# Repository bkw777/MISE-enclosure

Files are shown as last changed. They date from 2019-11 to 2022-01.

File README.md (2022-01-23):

## Enclosure for Peter Bartlett's MISE and M3SE.
http://bartlettlabs.com/MISE/index.html  
http://bartlettlabs.com/M3SE/index.html

Alt text for your video (https://youtu.be/Me62yHelnyM)

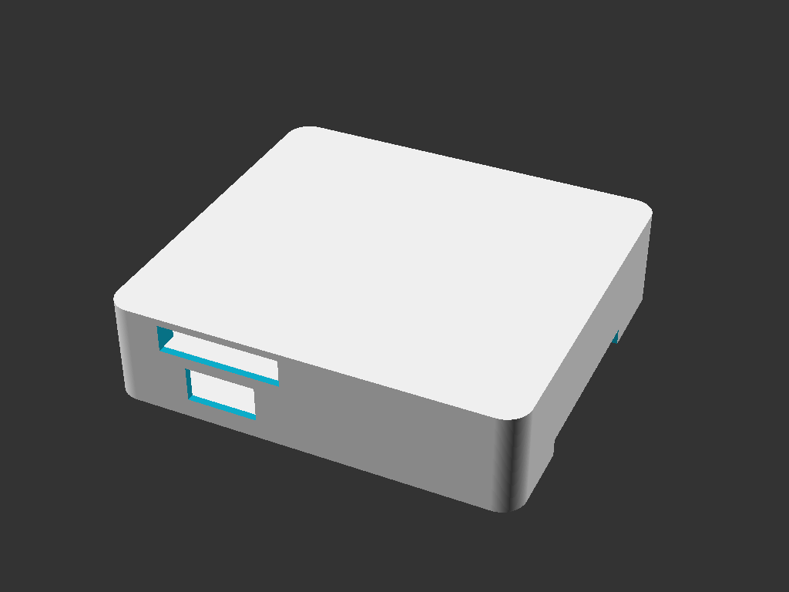
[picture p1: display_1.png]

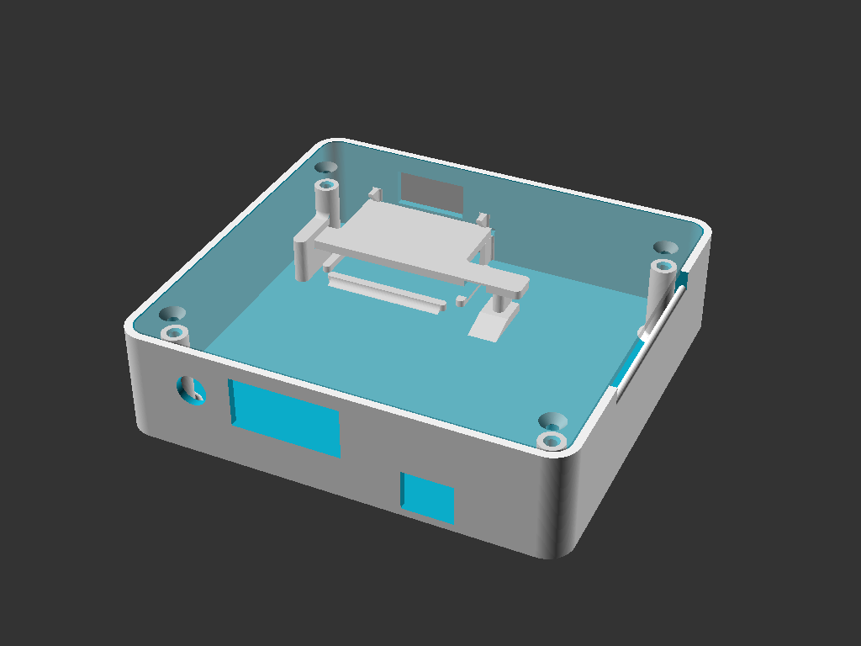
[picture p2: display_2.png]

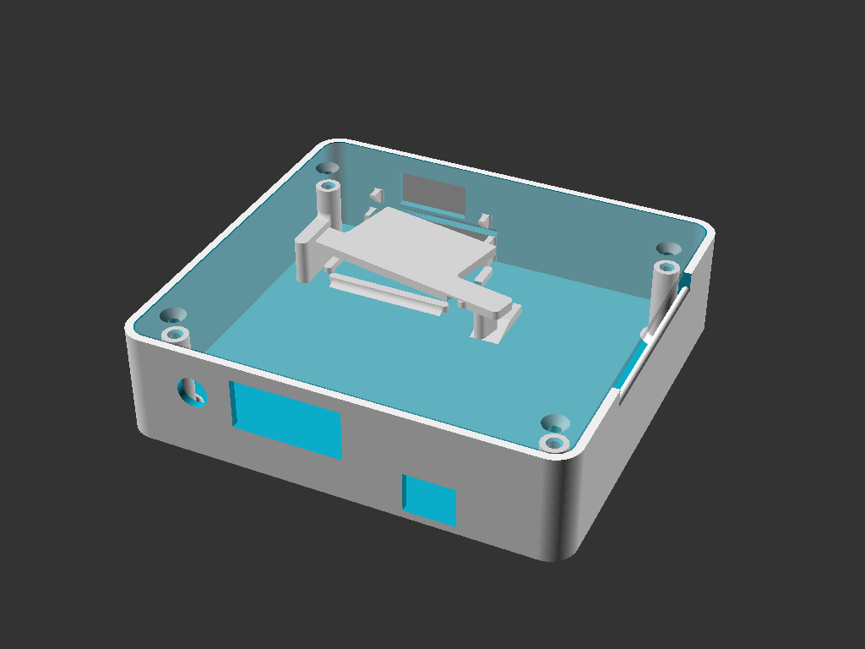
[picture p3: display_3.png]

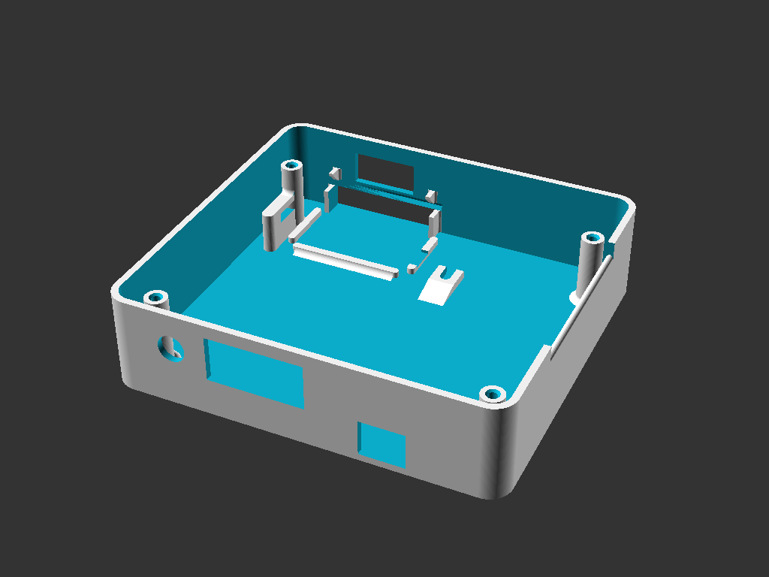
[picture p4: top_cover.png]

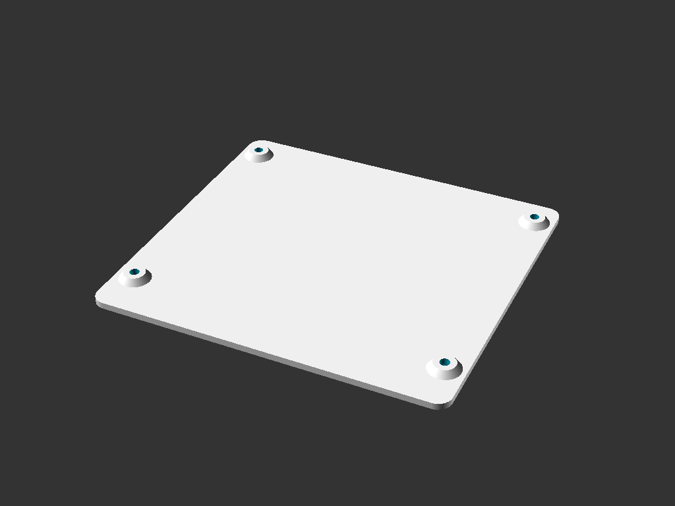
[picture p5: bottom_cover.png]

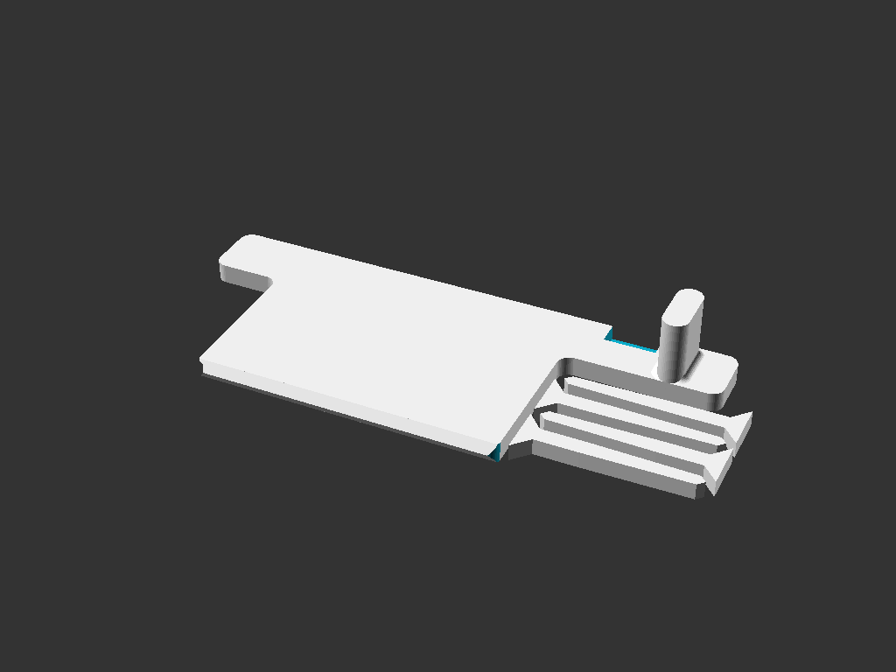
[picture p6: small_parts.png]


Pictures: https://photos.app.goo.gl/1NdcbL9hprvxRTdB7

STL files for 3d-printing are in [releases](../../releases/latest)

### Directions:

#### 1 - print the 3 files
 MISE_M3SE_top_cover_\<version\>.stl  
 MISE_M3SE_bottom_cover_\<version\>.stl  
 MISE_M3SE_small_parts_\<version\>.stl
 
 PLA, 20% infill, 3 walls is fine.

 Or buy a print from [CraftCloud](https://craftcloud3d.com/offer/18893031-29e2-49f1-acdd-6c543ac05efc)

#### 2 - Aquire the following parts

* **1 40-pin "IDE" male-female extension cable, 4 inch length**  
 It needs to be an extension, with one male and one female connector.  
 The direction the cable exits the connector on the *male* end matters. The cable should go *away* from the key notch in the side of the connector.  
 No extra fold / strain relief clip on the male connector.  
 No special requirements for the female connector.  
 
 http://www.cablesonline.com/240pinidedir.html  
 Change “Available Lengths: 4 inches FI-004”

* **4 flat-head #6 x 3/4" screws**  
 (These screws are optional: There are printed "nails" included in the small_parts stl which can be used in place of screws)  
 Home Depot:  
 https://www.homedepot.com/p/Everbilt-6-32-x-3-4-in-Phillips-Flat-Head-Stainless-Steel-Machine-Screw-6-Pack-814561/204274823

* **4 small rubber feet**  
 http://www.homedepot.com/p/Everbilt-1-2-in-Self-Adhesive-Vinyl-Surface-Bumpers-16-per-Pack-49967/203661150

#### 3 - Assembly
Unplug the CF reader from the mainboard & remove the CF card(s) from the reader.

Remove the 4 nylon stand-offs from the screw holes on the mainboard.

Plug the male end of the IDE extension cable onto the CF reader.

Lay the CF reader flat in the small tray formed into the corner of the top_cover, with the lights and jumpers up facing you.  
Install the retainer over top of the CF reader. (refer to pics)

Orient the top cover so that the network, vga, & power side is away from you.  
Set the mainboard standing up behind the 2 rear screw posts, network/vga/power side down.  

Connect the free end of the IDE extension cable to the IDE plug on the mainboard.

Lift the mainboard up from behind the 2 rear screw posts, tip forward toward yourself, and lay the mainboard flat atop all 4 screw posts.

Place the bottom cover on top of the mainboard, with the 4 short risers pointing down.

Install the 4 screws.

### Painting
A very close off-the-shelf match to the RCA "Mercedes Silver" TRS-80 paint is
[Dupli-Color Bumper Coating FB108 Medium Silver](http://www.amazon.com/Dupli-Color-FB108-Medium-Flexible-Coating/dp/B00296DXN4).

## Author / License

<br />This work is licensed under a <a rel="license" href="http://creativecommons.org/licenses/by-sa/4.0/">Creative Commons Attribution-ShareAlike 4.0 International License</a>.  
Brian K. White - b.kenyon.w@gmail.com

Designed with [OpenSCAD](https://www.openscad.org/)

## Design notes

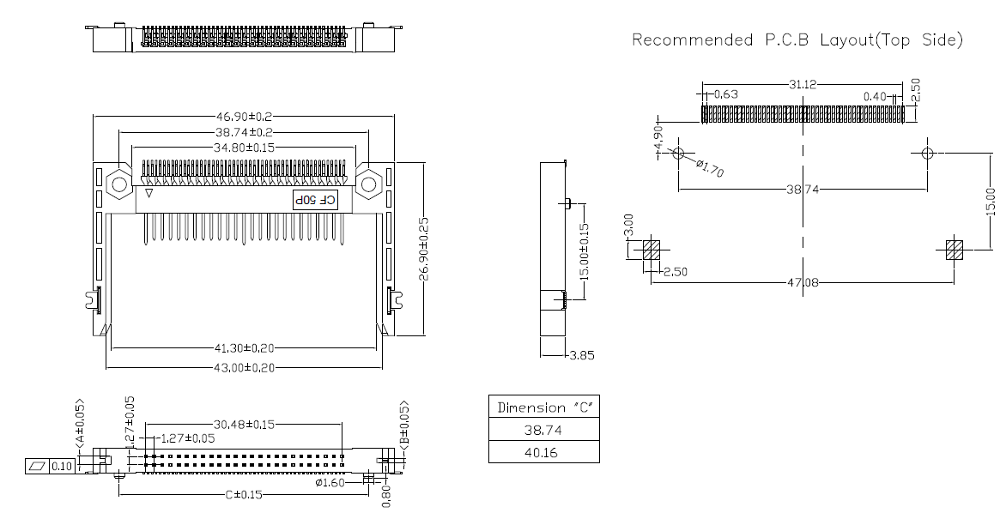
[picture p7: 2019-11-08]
ref/CF-50P.png

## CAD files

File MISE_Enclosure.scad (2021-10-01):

// M1SE/M3SE Enclosure - Top Cover
// b.kenyon.w@gmail.com

// Which version to generate, M1SE or M3SE
// The only difference is the width of the slot for the bus cable.
// M1SE has a 40-wire cable, M3SE has a 50-wire cable.
// M3SE version can be used for both M3SE and M1SE.
variant="M3SE";

// PCB dimensions
// https://groups.yahoo.com/neo/groups/TRS80MISE/conversations/topics/157
//  >  All hole centers are 250 mils from card edges, drilled for 187 mil board feet.
//  >  "Short edge" holes centered 3815 mils apart.
//  >  "Long edge" holes centered 4770 mils apart.
//  >  Thus the PCB is 4315x5270 mils.
px = 133.858; // pcb x len
py = 109.601; // pcb y len
pz = 0.1 + 1.6 + 0.1;     // pcb thickness
mi = 6.35;    // mounting holes inset from pcb edges
mhd = 4.75;   // mount hole diameter

// rear wall holes
vga_w = 35.814;
vga_h = 17.018;
vga_xc = -14.99;  // pcb X center to vga X center
vga_zb = -2.032;  // pcb Z top to vga Z bottom
pwr_r = 5.08;     // power radius
pwr_xc = -45.847; // pcb X center to power X center
pwr_zc = 6.604;   // pcb Z top to power Z center
nic_w = 16.51;
nic_h = 13.462;
nic_xc = 29.972;  // pcb X center to nic X center
nic_zt = 26.67;   // pcb Z top to nic Z top - NIC conector is the tallest top-side component, so normally you want "th" and "iw_h" to just copy this

// front wall holes
joy_h = 12.7;     // joystick height
joy_w = 22.86;    // joystick width
joy_xc = -30; // pcb center to js center
                  // joystick bottom = pcb top
joy_f = 5.1;      // pcb front edge to joystick front

cf_connector_thickness = 3.85 ; // references/CF-50P.png
cf_h = 0.1 + cf_connector_thickness + 0.1 + pz + 0.1 + cf_connector_thickness + 0.1 ; // cf height 9.9
cf_w = 43.18;    // cf width
                 // cf top = inside top surface = iw_h
cf_xc = joy_xc;  // cf x center

// right wall holes
bus_cable_conductors = (variant=="M1SE") ? 40 : 50;
bus_w = bus_cable_conductors * 1.27 + 1; // bus cable width
bus_h = 6.35;   // bus cable height
bus_yc = -5.33; // pcb center to bus cable center
                // bus cable z bottom = ew_z bottom

bch = 2.54;    // bottom-side components height - height of tallest bottom-side component (screw heads for heat sinks and connectors) from pcb bottom - inner/upper surface of base_plate rests here
tch = nic_zt;  // top-side components height - height of tallest top-side component (ethernet port) above pcb top - inner/lower surface of top wall rests here
assert(tch>=nic_zt,"tch must be >= nic_zt");
wt = 2.54;     // wall thickness - 2.54 makes the face of the ethernet port flush with the exterior surface

// NIC module pcb extends beyond the main pcb rear edge by this much.
// Rear vertical wall can be no closer to the main pcb than this.
// This just the nic module pcb,
// not including the rj45 connector which extends futher.
nic_pcb_overhang = 6.35; // nic module pcb overhang beyond main pcb edge

// FPGA module pcb extends past main pcb front edge by this much.
// Front vertical wall can be no closer to the main pcb than this.
fpga_pcb_overhang = 12.192; // fpga module pcb overhang beyond main pcb edge

// pcb edges to inside walls
f2w = fpga_pcb_overhang; // front pcb edge to front inside wall - must be fpga_pcb_overhang or greater
assert(f2w>=fpga_pcb_overhang,"f2w must be >= fpga_pcb_overhang");
l2w = 2;                 // left  pcb edge to left  inside wall - mise v1.1 has a heat-sink that overhangs about one mm or less on the left - v1.2 has no overhangs on the left
r2w = 2;                 // right pcb edge to right inside wall - no overhangs on the right, but the bus cable passes between the pcb and the wall.
assert(r2w>=1,"r2w must be enough to allow the bus cable to fit between the pcb and the enclosure wall.");
b2w = nic_pcb_overhang;  // back  pcb edge to back  inside wall - must be nic_pcb_overhang or greater
assert(b2w>=nic_pcb_overhang,"b2w must be >= nic_pcb_overhang");

// screw posts and countersinks
screw_d = 3.5;  // screw diameter - #6 = 0.14" = 3.5
screw_fhr = 4 ; // flat head radius
spir = screw_d/2-0.1; // screw post inside radius
spor = spir+2.5; // screw post outside radius

// interior walls
iw_x = l2w + px + r2w;
iw_y = f2w + py + b2w;
// This controls how high the top is above the highest component
iw_h = tch; // interior walls height - may be "tch" or greater
assert(iw_h>=tch,"iw_h must be >= tch");
iw_z = wt + bch + pz + iw_h; // total interior wall height

// exterior walls
ew_x = wt + iw_x + wt;  // total exterior X width
ew_y = wt + iw_y + wt;  // total exterior Y depth
ew_z = iw_z + wt;       // total exterior Z height

// wall corners radius, 0 to 13
// 0 = square corners
// 0.001 = square inside, round outside thickness of walls
// >0 = round corners
// >13 = invalid, hits pcb corners
cr = 6; // vertical corners inside radius

oc = 0.1;  // overcut - extend subtraction shapes past the edges of the shapes they cut from, to avoid making zero-thickness features
twt = 1.6; // tunnel wall thickness
p2t = 0.5; // any pcb edge pcb to any tunnel end

joy_t = f2w-joy_f-p2t; // joystick tunnel length

// CF reader
cft_w = 47.3; // cf tray inside width
cft_d = 27.3; // cf tray inside depth

// This controls how far the CF cards stick out of the front of the enclosure.
// This can vary from 0 to almost 9 in theory. (at 9 you would need fingernails to get the CF cards out)
cft_f2w = 5.842;  // cf tray inside front to inside front wall
//cft_f2w = 0;
                  // cf tray X center = cf opening X center = js_xc
cft_wt = 2.4;     // cf tray wall thickness
cft_wh = 2.54;    // cf tray wall height

cft_ow = cft_wt+cft_w+cft_wt; // cf tray outer walls
cft_otw = twt+cf_w+twt;       // cf tunnel outer walls

cft_cny = 4.83;    // cf tray clearance notch, inner tray rear to notch side
cft_cnl = 10.66;   // cf tray clearance notch, width
cft_cnh = 1.27;    // cf tray clearance notch, floor height (top wall inner surface to notch floor)

// cf reader retainer
// cf reader retainer top - cr_top is special
// The back side of the FPGA board comes down very close to the top of the JP2 jumper on the card reader.
// cr_top should be as high as possible, touching the FPGA board.
// This should allow about 1mm of plastic to cover the top of JP2 and act as a barrier to prevent JP2 from touching and shorting on the FPGA board.
// If really needed, you can increase iw_h, which will increase the distance between the fpga board and the card reader.
cr_top = 13; // highest surface on retainer bar

// cf retainer lid thickness
cr_lt = cr_top - cf_h;

cr_tab_w = 10;
cr_tab_wt = 3; // wall thickness around tab, all directions
//cr_tab_pocket_wall_thickness = spor*2;
cr_tab_pocket_wall_thickness = 6;
cr_tab_locx = px/2+cf_xc-mi-cft_w/2; // centered on screw post
cr_tab_pocket_wall_height = cr_top + 3;
cr_leg_w = 4;  // leg thickness
cr_tab_len = cr_tab_locx + cr_tab_pocket_wall_thickness/2; // for flush end, add "-cr_leg_w/2"
p_wall_y1 = f2w + mi;  // pocket wall front
p_wall_y2 = cft_f2w + cft_d + 5;  // pocket wall back
cr_tab_pocket_wall_length = p_wall_y2 - p_wall_y1;

// TODO - re-arrange this to be based off the edge of the reader pcb
//        this dim is left over from the previous style with a foot tab that goes into a pocket
// cf retainer latch block
cr_latch_locx = 18; // tray side to pocket side
cr_latch_handle = 12; // retainer bar extends past leg to make a finger-pull-able overhang

// smoother curves (less vibration while printing)
$fa = 0.5; // facet angle
$fs = 0.4; // facet size


///////////////////////////////////////////////////

module mirror_copy(vector){
  children();
  mirror(vector) children();
}

module walls() {
  difference() {
    group() { // add
      // exterior walls
      if(cr<=0) translate([-l2w-wt,-f2w-wt,-pz-bch-wt]) cube([ew_x,ew_y,ew_z]); // square corners
      else hull() {                                                             // round corners
        translate([-l2w+cr,-f2w+cr,-pz-bch-wt]) cylinder(ew_z,cr+wt,cr+wt);
        translate([px+r2w-cr,-f2w+cr,-pz-bch-wt]) cylinder(ew_z,cr+wt,cr+wt);
        translate([-l2w+cr,py+b2w-cr,-pz-bch-wt]) cylinder(ew_z,cr+wt,cr+wt);
        translate([px+r2w-cr,py+b2w-cr,-pz-bch-wt]) cylinder(ew_z,cr+wt,cr+wt);
      }

    } // add
    group() { // remove
      // interior walls
      if(cr<=0) translate([-l2w,-f2w,-pz-bch-wt-wt]) cube([iw_x,iw_y,ew_z]);  // square corners
      else hull() {                                                           // round corners
        translate([-l2w+cr,-f2w+cr,-pz-bch-wt-oc]) cylinder(ew_z-wt+oc,cr,cr);
        translate([px+r2w-cr,-f2w+cr,-pz-bch-wt-oc]) cylinder(ew_z-wt+oc,cr,cr);
        translate([-l2w+cr,py+b2w-cr,-pz-bch-wt-oc]) cylinder(ew_z-wt+oc,cr,cr);
        translate([px+r2w-cr,py+b2w-cr,-pz-bch-wt-oc]) cylinder(ew_z-wt+oc,cr,cr);
      }
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

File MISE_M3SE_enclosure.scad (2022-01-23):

// M1SE/M3SE Enclosure - Top Cover
// b.kenyon.w@gmail.com
// version: 2.2.005

// Which version to generate, M1SE or M3SE
// The only difference is the width of the slot for the bus cable.
// M1SE has a 40-wire cable, M3SE has a 50-wire cable.
// M3SE version can be used for both M3SE and M1SE.
variant = "M3SE";

// Normally Makefile sets this.
// "none", "top_cover", "bottom_cover", "retainer", "nail", "small_parts"
// "display_1", "display_2", "display_3", "display_nail"
make = "display_2";

$fs = 0.25;
$fa = 1;
o = 0.01; // overlap/overcut - extend unions/cuts past boundaries
fc = 0.1; // part fitment clearance
fr = 1;   // default fillet radius

// PCB dimensions
// https://groups.yahoo.com/neo/groups/TRS80MISE/conversations/topics/157
//  >  All hole centers are 250 mils from card edges, drilled for 187 mil board feet.
//  >  "Short edge" holes centered 3815 mils apart.
//  >  "Long edge" holes centered 4770 mils apart.
//  >  Thus the PCB is 4315x5270 mils.
px = 133.858; // pcb x len
py = 109.601; // pcb y len
pcb_thickness = 1.6;
pz = fc + pcb_thickness + fc;
mi = 6.35;    // mounting holes inset from pcb edges
mhd = 4.75;   // mount hole diameter

// rear wall holes
vga_w = 35.814;
vga_h = 17.018;
vga_xc = -14.99;  // pcb X center to vga X center
vga_zb = -2.032;  // pcb Z top to vga Z bottom
pwr_r = 5.08;     // power radius
pwr_xc = -45.847; // pcb X center to power X center
pwr_zc = 6.604;   // pcb Z top to power Z center
nic_w = 16.51;
nic_h = 13.462;
nic_xc = 29.972;  // pcb X center to nic X center
nic_zt = 26.67;   // pcb Z top to nic Z top - NIC conector is the tallest top-side component, so normally you want "th" and "iw_h" to just copy this

// front wall holes
joy_h = 12.7;     // joystick height
joy_w = 25; //22.86;    // joystick width
joy_xc = -30;     // pcb center to js center
                  // joystick bottom = pcb top
joy_f = 5.1;      // pcb front edge to joystick front

cf_connector_thickness = 3.85 ; // references/CF-50P.png
cf_h = 0.1 + cf_connector_thickness + 0.1 + pz + 0.1 + cf_connector_thickness + 0.1 ; // cf height 9.9
cf_w = fc+43.1+fc;    // cf width
                 // cf top = inside top surface = iw_h
cf_xc = joy_xc;  // cf x center

// right wall holes
bus_cable_conductors = (variant=="M1SE") ? 40 : 50;
bus_w = bus_cable_conductors * 1.27 + 1; // bus cable width
bus_h = 6.35;   // bus cable height
bus_yc = -5.33; // pcb center to bus cable center
                // bus cable z bottom = ew_z bottom

bch = 2.54;    // bottom-side components height - height of tallest bottom-side component (screw heads for heat sinks and connectors) from pcb bottom - inner/upper surface of base_plate rests here
tch = nic_zt;  // top-side components height - height of tallest top-side component (ethernet port) above pcb top - inner/lower surface of top wall rests here
assert(tch>=nic_zt,"tch must be >= nic_zt");
wt = 2.54;     // wall thickness - 2.54 makes the face of the ethernet port flush with the exterior surface

// NIC module pcb extends beyond the main pcb rear edge by this much.
// Rear vertical wall can be no closer to the main pcb than this.
// This just the nic module pcb,
// not including the rj45 connector which extends futher.
nic_pcb_overhang = 6.35; // nic module pcb overhang beyond main pcb edge

// FPGA module pcb extends past main pcb front edge by this much.
// Front vertical wall can be no closer to the main pcb than this.
fpga_pcb_overhang = 12.192; // fpga module pcb overhang beyond main pcb edge

// pcb edges to inside walls
f2w = fpga_pcb_overhang; // front pcb edge to front inside wall - must be fpga_pcb_overhang or greater
assert(f2w>=fpga_pcb_overhang,"f2w must be >= fpga_pcb_overhang");
l2w = 2;                 // left  pcb edge to left  inside wall - mise v1.1 has a heat-sink that overhangs about one mm or less on the left - v1.2 has no overhangs on the left
r2w = 2;                 // right pcb edge to right inside wall - no overhangs on the right, but the bus cable passes between the pcb and the wall.
assert(r2w>=1.27,"r2w must be enough to allow the bus cable to fit between the pcb and the enclosure wall.");
b2w = nic_pcb_overhang;  // back  pcb edge to back  inside wall - must be nic_pcb_overhang or greater
assert(b2w>=nic_pcb_overhang,"b2w must be >= nic_pcb_overhang");

// screw posts and countersinks
screw_d = 3.5;  // screw diameter - #6 = 0.14" = 3.5
screw_fhr = 4 ; // flat head radius
spir = screw_d/2-0.1; // screw post inside radius
spor = spir+2.5; // screw post outside radius
screw_post_fillet = 2.5;
screw_post_chamfer = 0.75;

// printable flat nail that can be used in place of screw
// nail length not counting head
nail_length = 20 + pcb_thickness + bch;

// square nail cross-section diagonal width, percent of screw post ID
// 0 = corners of nail body exactly the same is screw hole ID
// -n = diagonal x% smaller than hole
// +n = diagonal x% larger than hole
nail_interference_fit_percent = 10;

// how far the full-width non-tapered part of the nail shank inserts into the screw post
// 0 = nail is only full width in the PCB and bottom cover
//     tapers from 75% to full width over the remaining length
nail_grip_depth = 0;

nail_full_width = sq_in_circle(spir*2) * (100+nail_interference_fit_percent)/100;
nail_tip_width = nail_full_width * 0.75;

// interior walls
iw_x = l2w + px + r2w;
iw_y = f2w + py + b2w;
// This controls how high the top is above the highest component
iw_h = tch; // interior walls height - may be "tch" or greater
assert(iw_h>=tch,"iw_h must be >= tch");
iw_z = wt + bch + pz + iw_h; // total interior wall height

// exterior walls
ew_x = wt + iw_x + wt;  // total exterior X width
ew_y = wt + iw_y + wt;  // total exterior Y depth
ew_z = iw_z + wt;       // total exterior Z height

// wall corners radius, 0 to 13
// 0 = square corners
// 0.001 = square inside, round outside thickness of walls
// >0 = round corners
// >13 = invalid, hits pcb corners
cr = 6; // vertical corners inside radius

twt = 2; // tunnel wall thickness
p2t = 0.5; // any pcb edge pcb to any tunnel end

joy_t = f2w-joy_f-p2t; // joystick tunnel length

// CF reader
cft_w = 47.3; // cf tray inside width
cft_d = 27.3; // cf tray inside depth

// This controls how far the CF cards stick out of the front of the enclosure.
// This can vary from 0 to almost 9 in theory. (at 9 you would need fingernails to get the CF cards out)
cft_f2w = 5.842;  // cf tray inside front to inside front wall
//cft_f2w = 0;
                  // cf tray X center = cf opening X center = js_xc
cft_wt = 3;      // cf tray wall thickness
cft_wh = 2.4;    // cf tray wall height

cft_ow = cft_wt+cft_w+cft_wt; // cf tray outer walls
cft_otw = twt+cf_w+twt;       // cf tunnel outer walls

cft_cny = 4.83;    // cf tray clearance notch, inner tray rear to notch side
cft_cnl = 10.66;   // cf tray clearance notch, width
cft_cnh = 1.27;    // cf tray clearance notch, floor height (top wall inner surface to notch floor)

// cf reader retainer
// cf reader retainer top - cr_top is special
// The back side of the FPGA board comes down very close to the top of the JP2 jumper on the card reader.
// cr_top should be as high as possible, touching the FPGA board.
// This should allow about 1mm of plastic to cover the top of JP2 and act as a barrier to prevent JP2 from touching and shorting on the FPGA board.
// If really needed, you can increase iw_h, which will increase the distance between the fpga board and the card reader.
cr_top = 13; // highest surface on retainer bar

// cf retainer lid thickness
cr_lt = cr_top - cf_h;

cr_tab_w = 10; // retainer tab width
cr_tab_wt = 3; // wall thickness around tab
cr_tab_pocket_wall_thickness = 5; // spor*2;
cr_tab_locx = px/2+cf_xc-mi-cft_w/2; // centered on screw post
cr_tab_pocket_wall_height = cr_top + 3;
cr_leg_w = 4;  // leg thickness
cr_tab_len = cr_tab_locx + cr_tab_pocket_wall_thickness/2-cr_leg_w/2-fc; // for flush end, add "-cr_leg_w/2"
p_wall_y1 = f2w + mi;  // pocket wall front
p_wall_y2 = cft_f2w + cft_d + 5;  // pocket wall back
cr_tab_pocket_wall_length = p_wall_y2 - p_wall_y1;

// TODO - re-arrange this to be based off the edge of the reader pcb
//        this dim is left over from the previous style with a foot tab that goes into a pocket
// cf retainer latch block
cr_latch_locx = 18; // tray side to pocket side
cr_latch_handle = 6; // retainer bar extends past leg to make a handle

include <handy.scad>;

///////////////////////////////////////////////////

function sq_in_circle(d) = d * sqrt(2)/2;
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

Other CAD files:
handy.scad

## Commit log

2016-03-14 Initial commit. This version mostly works, but does need a little manual hacking after printing. The posts on the base plate should be shortened to 0.1 inch (just cut off the cylindrical post part an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
    [MISE_base_plate.FCStd, MISE_base_plate.stl, MISE_cf_retainer.FCStd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]
2016-03-14 Correct placement of front and rear wall openings. Move cf retainer closed slot closer to reader. Trim unnecessary height of cf retainer open slot post.. Lengthen and move forward cf retainer open sl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
    [MISE_base_plate.FCStd, MISE_base_plate.stl, MISE_top_cover.FCStd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]
2016-03-14 Round the 4 vertical outside corners to look more like trs-80 and accessories. (although, trs-80 and accessories round the horizontal front and rear edges, not the vertical edges)
    [MISE_base_plate.FCStd, MISE_base_plate.stl, MISE_top_cover.FCStd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]
2016-03-25 Removed junk extra line13 from cf retainer base sketch. Repaired cf retainer closed slot pocket sketch came off it's face. Adjusted length and shape of cf retainer open slot a little. Resolved confli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
2016-03-26 Main dimensions and shape adjusted for v1.2 enclosure. Also: * cutouts to allow retainer to swing far enough to install/remove o clearance for JP1 & JP2 o drop leg when twisted * solid block padding 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
    [MISE_cf_retainer.FCStd, MISE_cf_retainer.stl]
2016-04-22 Several corrections to cf retainer. M3SE option, only difference is wider ribbon cable opening.
    [M3SE_top_cover.stl, MISE_cf_retainer.FCStd, MISE_cf_retainer.stl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]
2019-10-07 initial .scad
    [Top_Cover.scad]
2019-10-11 conditional corners, show pcb, comments, smooth arcs
    [Top_Cover.scad]
2019-10-29 archive FreeCAD files, finish OpenSCAD model
    [M3SE_top_cover.stl, MISE_Enclosure.scad, MISE_base_plate.FCStd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]
2019-10-31 tweak the retainer bar tabs & slots
    [MISE_Enclosure.scad, bottom_cover.stl, retainer.stl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]
2019-11-02 strengthen retainer, adjust retainer fitment
    [MISE_Enclosure.scad, bottom_cover.stl, retainer.stl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]
2019-11-02 docs & images
    [MISE_Enclosure.scad, bottom_cover.stl, retainer.stl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]
2019-11-02 retainer heel clearance while opening/closing, screw posts id & od, bottom cover screw holes id
    [MISE_Enclosure.scad, bottom_cover.stl, retainer.stl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]
2019-11-04 new retainer design that's simpler to use and simpler to print
    [MISE_Enclosure.scad, bottom_cover.stl, retainer.stl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]
2019-11-04 retainer printing orientation
    [MISE_Enclosure.scad]
2019-11-04 update renders
    [bottom_cover.stl, retainer.stl, top_cover.stl]
2019-11-04 update retainer-open render
    [MISE_Enclosure.scad, bottom_cover.stl, retainer.stl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]
2019-11-08 remove difficult to print overhangs
    [MISE_Enclosure.scad, bottom_cover.stl, retainer.stl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]
2019-11-09 strengthen pocket wall against the force from the retainer bar twisting and prising the slot open. Add front lid guide. Increase clearance in latch around leg.
    [MISE_Enclosure.scad, bottom_cover.stl, retainer.stl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]
2019-11-09 fix retainer position in renders
    [MISE_Enclosure.scad, bottom_cover.stl, top_cover.stl]
2019-11-12 replace some right-angles in the cf-tray with round ends to make it more FDM friendly.
    [MISE_Enclosure.scad, bottom_cover.stl, retainer.stl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]
2019-11-12 rename orig dir
    [M3SE_top_cover.stl, MISE_base_plate.FCStd, MISE_base_plate.stl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]
2021-10-01 cylinder() syntax in the leg latch pocket
    [MISE_Enclosure.scad, bottom_cover.stl, retainer.stl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]
2022-01-10 remove stl's to release assets
    [bottom_cover.stl, retainer.stl, top_cover.stl]
2022-01-10 remove orig directory to a v1.x tag and release
    [M3SE_top_cover.stl, MISE_base_plate.FCStd, MISE_base_plate.stl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]
2022-01-10 add fillets, add nails, looser fit for cf tray
    [MISE_M3SE_enclosure.scad, handy.scad]
2022-01-11 fix makefile make=... variable and stl filename
2022-01-12 front edge of retainer
    [MISE_M3SE_enclosure.scad]
2022-01-16 nail width, cf hole width
    [MISE_M3SE_enclosure.scad]
2022-01-23 cf reader holder fit
    [MISE_M3SE_enclosure.scad]
